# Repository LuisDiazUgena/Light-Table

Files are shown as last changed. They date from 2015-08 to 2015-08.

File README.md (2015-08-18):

# Light-Table

Light Table design files & Firmware

##Arduino shield

###Regulated version
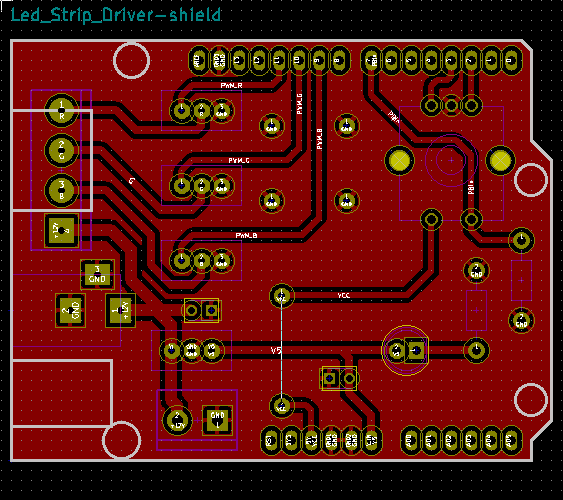
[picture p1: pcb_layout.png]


Arduino shield drives from 12V DC Jack (Center positive) and power Arduino through a voltage regulator (LM7805/Murata 7805SRH-C) with decoupling caps. Works with pwm to control Mosfets (IRF3205) (Up to 1.2A/Mosfet).

**If using Murata 7805SRH-C do not use decoupling caps, there is no need for it.**

### Non regulated version

Power the whole thing with 12V connected on the DC Jack of the shield (**Do not connect other jack on the board**). If your board is a cheap clone or you are not sure that it got a good regulator or protection, use regulated version.

##Arduino Firmware

Support single or long click: Single click put FW in color selection mode and long click clears the leds.
Control color over Bluetooth and Android/Protocoder App.

##Android Apps
###Protocoder

Protocoder app is used to control color on the light table over Bluetooth. You can download both code and project from Android apps folder.

###App Inventor

App Inventor app is used to control color on the light table over Bluetooth. You can download both code and project from Android apps folder.

##Hardware Used

<table>
  <tr>
    <th class="tg-031e">Reference</th>
    <th class="tg-031e">Value</th>
  </tr>
  <tr>
    <td class="tg-031e">C1</td>
    <td class="tg-031e">100uF</td>
  </tr>
  <tr>
    <td class="tg-031e">C2</td>
    <td class="tg-031e">10uF</td>
  </tr>
  <tr>
    <td class="tg-031e">CON1</td>
    <td class="tg-031e">BARREL_JACK</td>
  </tr>
  <tr>
    <td class="tg-031e">D1</td>
    <td class="tg-031e">PWR</td>
  </tr>
  <tr>
    <td class="tg-031e">EN1</td>
    <td class="tg-031e">ENCODER_5_PINS</td>
  </tr>
  <tr>
    <td class="tg-031e">P1</td>
    <td class="tg-031e">Screw Block 2</td>
  </tr>
  <tr>
    <td class="tg-031e">P8</td>
    <td class="tg-031e">Screw Block 4</td>
  </tr>
  <tr>
    <td class="tg-031e">R1</td>
    <td class="tg-031e">10K</td>
  </tr>
  <tr>
    <td class="tg-031e">R2</td>
    <td class="tg-031e">330</td>
  </tr>
  <tr>
    <td class="tg-031e">SHIELD1</td>
    <td class="tg-031e">ARDUINO_SHIELD</td>
  </tr>
  <tr>
    <td class="tg-031e">U1</td>
    <td class="tg-031e">IRF3205</td>
  </tr>
  <tr>
    <td class="tg-031e">U2</td>
    <td class="tg-031e">IRF3205</td>
  </tr>
  <tr>
    <td class="tg-031e">U3</td>
    <td class="tg-031e">IRF3205</td>
  </tr>
  <tr>
    <td class="tg-031e">U4</td>
    <td class="tg-031e">LM7805</td>
  </tr>
</table>

##Issues

### 1: Inefficient power regulation (n = 0.41667).

Generates so much heat. Solutions:

1. Change Lm7805 module to 78XXSR Murata switching regulator.
2. Add a Heatsink (Still to much heat) and a fan.

By using a efficient power regulation will not need to use heat sink and/or fan.

Will change LM7805 module to a 7805SRH-C module. efficiency graph:

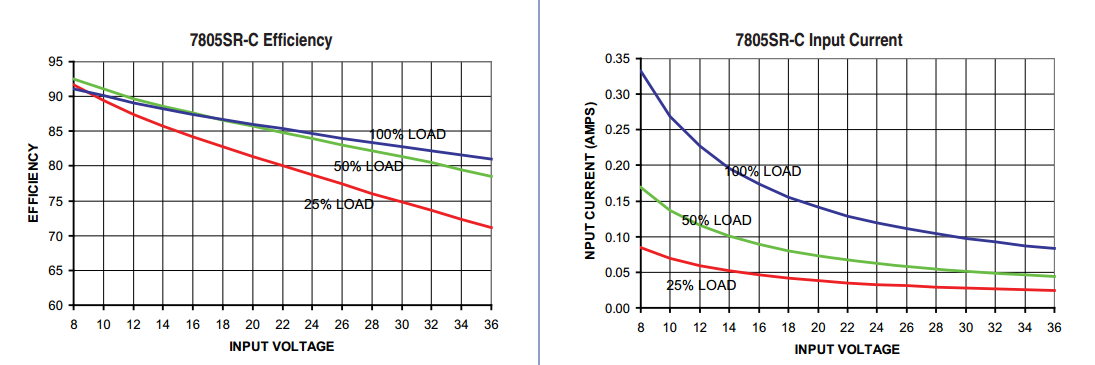
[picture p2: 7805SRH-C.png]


As it will have 12V as input voltage will get from 87 to 90% efficiency.

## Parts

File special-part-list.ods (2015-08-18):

Part Name | Units | Link
Murata 7805 SRH-C | 1 | http://www.mouser.es/ProductDetail/Murata-Power-Solutions/7805SRH-C/
IRF3205 | 3 | http://www.mouser.es/ProductDetail/International-Rectifier/IRF3205ZLPBF/
Encoder rotacional | 1 | http://www.ebay.es/itm/Set-de-2-encoders-rotatorios-12-mm-lado-y-eje-6-mm-diametro-con-pulsador-eje-/111631431636
Barrier terminal block | 3 | http://www.mouser.es/search/ProductDetail.aspx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

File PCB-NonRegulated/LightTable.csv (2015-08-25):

Reference | Value | Footprint | Datasheet
SHIELD1 | ARDUINO_SHIELD | arduino_shields:ARDUINO_SHIELD_2_040pins
EN1 | ENCODER_5_PINS | library:ENCODER_5_PINS
R1 | 10K | Resistors_ThroughHole:Resistor_Horizontal_RM10mm
U1 | MosfetIRF | library:IRF3205
U2 | MosfetIRF | library:IRF3205
U3 | MosfetIRF | library:IRF3205
CON1 | BARREL_JACK | library:BARREL_JACK
P1 | CONN_2_V | borniers:bornier2_V
P2 | CONN_01X01 | library:header1x01
P7 | CONN_01X01 | library:header1x01
P4 | CONN_01X01 | library:header1x01
P3 | CONN_01X01 | library:header1x01
P6 | CONN_01X01 | library:header1x01
P5 | CONN_01X01 | library:header1x01
P8 | CONN_4_V | borniers:bornier4_V
D2 | Long | LEDs:LED-5MM
R3 | 330 | Resistors_ThroughHole:Resistor_Horizontal_RM10mm
R2 | 330 | Resistors_ThroughHole:Resistor_Horizontal_RM10mm
D1 | PWR | LEDs:LED-5MM

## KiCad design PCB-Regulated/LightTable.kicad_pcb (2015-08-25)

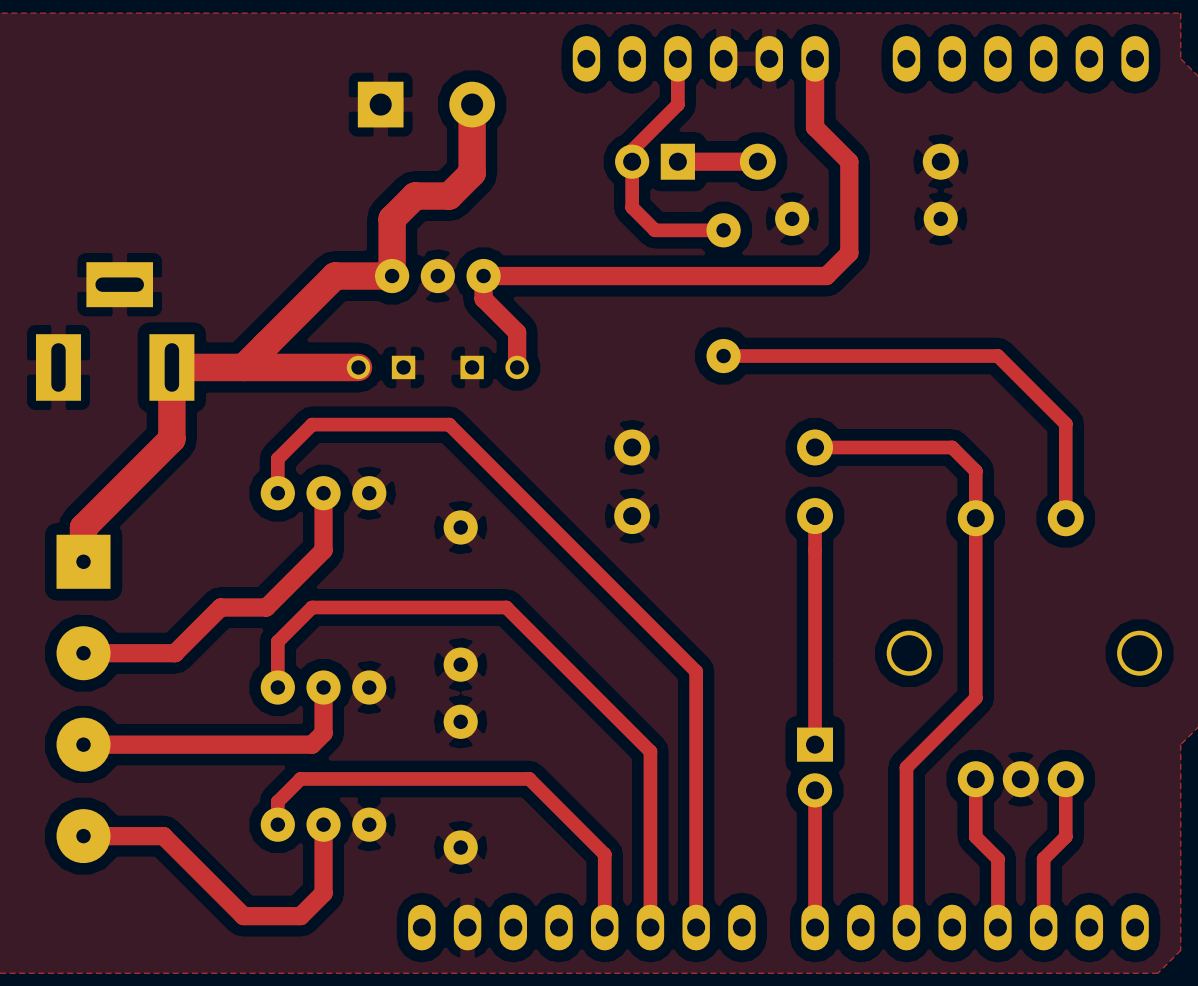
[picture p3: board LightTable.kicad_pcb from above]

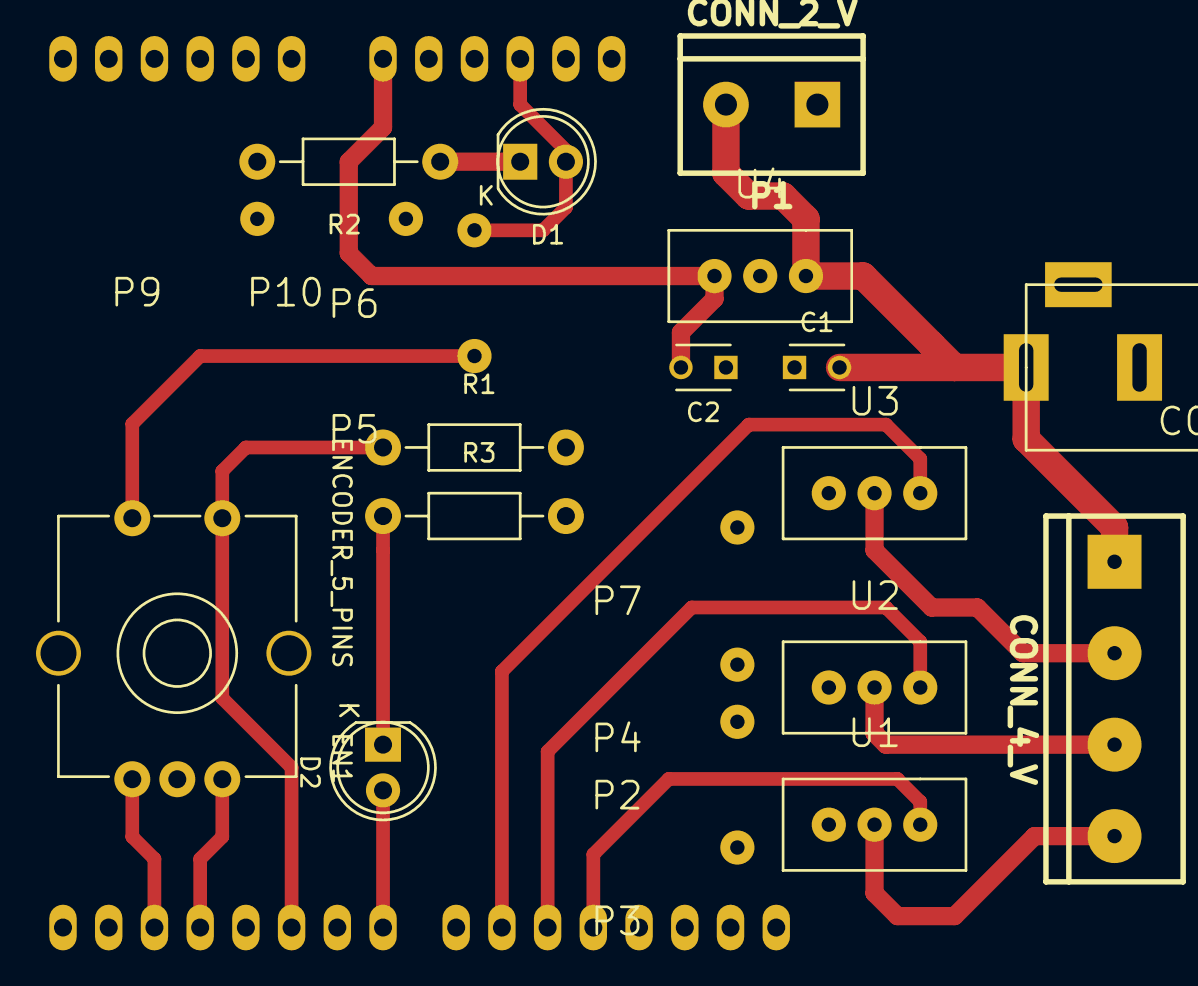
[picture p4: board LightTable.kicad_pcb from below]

Board: 2 copper layers, 24 parts (24 on the bottom side), 16 nets.

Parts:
C1: 100uF; C_Disc_D3_P2.5
C2: 10uF; C_Disc_D3_P2.5
CON1: BARREL_JACK
D1: PWR; LED-5MM
D2: Long; LED-5MM
EN1: ENCODER_5_PINS
P1: CONN_2_V; bornier2_V
P2, P3, P4, P5, P6, P7, P9, P10: CONN_01X01; header1x01
P8: CONN_4_V; bornier4_V
R1: 10K; Resistor_Horizontal_RM10mm
R2, R3: 330; Resistor_Horizontal_RM10mm
SHIELD1: ARDUINO_SHIELD; ARDUINO_SHIELD_2_040pins
U1, U2, U3: MosfetIRF; IRF3205
U4: LM7805

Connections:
+12V: C1.2, CON1.1, P1.2, P8.4, U4.VI
B: P8.3, U3.2
G: P8.2, U2.2
GND: C1.1, C2.1, CON1.2, CON1.3, EN1.2, P1.1, P2.1, P3.1, P4.1, P7.1, P9.1, P10.1, R1.2, R2.2, R3.2, SHIELD1.GND1, SHIELD1.GND2, SHIELD1.GND3, U1.3, U2.3, U3.3, U4.GND
unnamed: D1.1, R2.1
unnamed: D2.1, R3.1
unnamed: D2.2, SHIELD1.7
unnamed: EN1.1, SHIELD1.3
unnamed: EN1.3, SHIELD1.2
PBtn: EN1.5, R1.1, SHIELD1.5
PWM_B: SHIELD1.9, U3.1
PWM_G: SHIELD1.10, U2.1
PWM_R: SHIELD1.11, U1.1
R: P8.1, U1.2
V5: C2.2, SHIELD1.V_IN, U4.VO
VCC: D1.2, EN1.4, P5.1, P6.1, SHIELD1.5V

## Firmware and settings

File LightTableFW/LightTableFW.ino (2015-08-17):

/*

Light table FW

*/

//Encoder variables
//interrupt 0 (pin 2) and interrupt 1 (pin 3)
int encoderPin1 = 3;
int encoderPin2 = 2;
int encoderSwitchPin = 5; //push button switch

int pinledLong = 7;

int sum;

volatile int lastEncoded = 3; //You must initialize the encoders pins on 11 (3) !!!
volatile long encoderValue = 0;

long lastencoderValue = 0;

int lastMSB = 0;
int lastLSB = 0;

//debug
bool debug = false;

//led strip
int pinR = 11, pinG = 10, pinB = 9; // PWM pins
int color = 0; // 0:red, 1: green, 2:blue
int red = 255, green = 255, blue = 255;

//Time variables
long unsigned nextTime, intervale = 1000; // Change intervale to modify long time click
bool clicked = false;

//Fan
int pinFan = 4;
bool fanOn = false;
void setup() {

  Serial.begin (19200); // Needs to be 19200 to work with ZUM BT-328 Bluetooth.

  //Encoder pins
  pinMode(encoderPin1, INPUT);
  pinMode(encoderPin2, INPUT);

  pinMode(encoderSwitchPin, INPUT);

  pinMode(pinFan, OUTPUT);

  digitalWrite(encoderPin1, HIGH); //turn pullup resistor on
  digitalWrite(encoderPin2, HIGH); //turn pullup resistor on

  //call updateEncoder() when any high/low changed seen
  //on interrupt 0 (pin 2), or interrupt 1 (pin 3)
  attachInterrupt(0, updateEncoder, CHANGE);
  attachInterrupt(1, updateEncoder, CHANGE);

  //Led strip pins
  pinMode(pinR, OUTPUT);
  pinMode(pinG, OUTPUT);
  pinMode(pinB, OUTPUT);

  // turn off leds by default at boot
  clear();

}

void loop() {

/*
  Bluetooth functions
*/

if(Serial.available()>0){
  red = Serial.parseInt();
  green = Serial.parseInt();
  blue = Serial.parseInt();

  if(Serial.read()=='\n'){
    red = constrain(red,0,255);
    green = constrain(green,0,255);
    blue = constrain(blue,0,255);

    analogWrite(pinR, red);
    analogWrite(pinG, green);
    analogWrite(pinB, blue);
  }
}

/*
  Encoder functions
*/

  nextTime = millis() + intervale;
  while (digitalRead(encoderSwitchPin)) {
    clicked = true;
    if(millis()>nextTime){
      digitalWrite(pinledLong, HIGH);
    }
  }
  digitalWrite(pinledLong, LOW);

  if (clicked) {
    if (millis() > nextTime) {
      //Long click
      if(encoderValue==0){
        fanOn=true;
        AllOn();
      }else{
        fanOn=false;
        clear();
      }
    } else {
      //Short click
      manageColor();
    }
    clicked = false;
  }else{
    if(lastencoderValue != encoderValue){
      updateAllColors(encoderValue);
    }
  }

  /*
    Fan functions
  */

  if (fanOn){
    digitalWrite(pinFan, HIGH);
  }else{
    digitalWrite(pinFan, LOW);
  }

  delay(100); //just here to slow down the output, and show it. will work even during a delay
}

void updateAllColors(int value){
  analogWrite(pinR, value);
  analogWrite(pinG, value);
  analogWrite(pinB, value);
}
void AllOn(){
  encoderValue=255;
  updateAllColors(encoderValue);
}
void clear(){
  encoderValue=0;
  updateAllColors(encoderValue);
}
int manageColor() {
  delay(250);
  if (debug){
    Serial.print("color = ");
    Serial.println(color);
  }

  encoderValue = 0;
  if (color == 0) {
    clear();
  }

  do {
    if (color == 0) {
      //Red is changing
      red = encoderValue;
      analogWrite(pinR, red);
    } else if (color == 1) {
      //Green is changing
      green = encoderValue;
      analogWrite(pinG, green);
    } else if (color == 2) {
      //Blue is changing
      blue = encoderValue;
      analogWrite(pinB, blue);
    }
  } while (!digitalRead(encoderSwitchPin));

  color++;

  if (color != 3) {
    manageColor();
  } else {
    /*
    analogWrite(pinR, red);
    analogWrite(pinG, green);
    analogWrite(pinB, blue);
    */
    color = 0;
    delay(250);
    return 0;
  }

}
void updateEncoder() {

  int MSB = digitalRead(encoderPin1); //MSB = most significant bit
  int LSB = digitalRead(encoderPin2); //LSB = least significant bit

  int encoded = (MSB << 1) | LSB; //converting the 2 pin value to single number

  sum  = (lastEncoded << 2) | encoded; //adding it to the previous encoded value

  if (sum == 0b1101 || sum == 0b0100 || sum == 0b0010 || sum == 0b1011) encoderValue ++;
  if (sum == 0b1110 || sum == 0b0111 || sum == 0b0001 || sum == 0b1000) encoderValue --;

  encoderValue = constrain(encoderValue,0,255); //Fixed encoder value to 0-255 range

  if (debug) {
    Serial.print("lastencoded: ");
    Serial.println(lastEncoded);

    Serial.print("encoded: ");
    Serial.println(encoded);
  }
  if(encoderValue == 0){
    fanOn = false;
  }else{
    fanOn =true;
  }
  lastEncoded = encoded; //store this value for next time
}

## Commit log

2015-06-19 changed trimmer pin to free XTAL pins to add a 16MHz crystal
2015-06-19 Added schematich, attiny and icsp libraries
    [LightTable.sch]
2015-08-12 Working on a shield
    [LightTable.sch]
2015-08-13 Added pcb layout and libraries
    [LightTable.kicad_pcb, LightTable.sch]
2015-08-13 Moved encoder to .pretty folder
2015-08-13 Added Power Led and BOM
    [LightTable.csv, LightTable.kicad_pcb, LightTable.sch]
2015-08-13 Added image of pcb layout
2015-08-13 Added svg file
    [LightTable.kicad_pcb]
2015-08-13 Added support for encoder. Started working on led control
2015-08-13 Added led support
2015-08-13 Remove println info or moved into debug
2015-08-14 Added long click for turning on/off the leds
2015-08-17 Fixed bug-after a long click doesn't turn off
    [LightTableFW.ino]
2015-08-17 Changed capacitor values
    [LightTable.kicad_pcb]
2015-08-17 Added led for showing when a long click has been made
    [LightTable.kicad_pcb, LightTable.sch]
2015-08-18 Added links to special parts used
    [special-part-list.ods]
2015-08-18 Minor changes
    [LightTable.kicad_pcb]
2015-08-18 Changed folder name
    [LightTable.csv, LightTable.kicad_pcb, LightTable.sch]
2015-08-18 Created shield that uses voltage regulator in the board
    [LightTable.csv, LightTable.kicad_pcb, LightTable.sch]
2015-08-18 Added info about pcb versions
2015-08-20 Fixed wrong placement of shield and added gerbers
    [LightTable.kicad_pcb, LightTable.sch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]
2015-08-20 Fixed wrong placement of shield
    [LightTable.kicad_pcb, LightTable.sch]
2015-08-20 Added GND jumper to improve ground connectivity
    [LightTable.sch]
2015-08-25 Added gerbers
    [LightTable.csv, LightTable.kicad_pcb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]
2015-08-25 improved pads
    [LightTable.kicad_pcb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]
